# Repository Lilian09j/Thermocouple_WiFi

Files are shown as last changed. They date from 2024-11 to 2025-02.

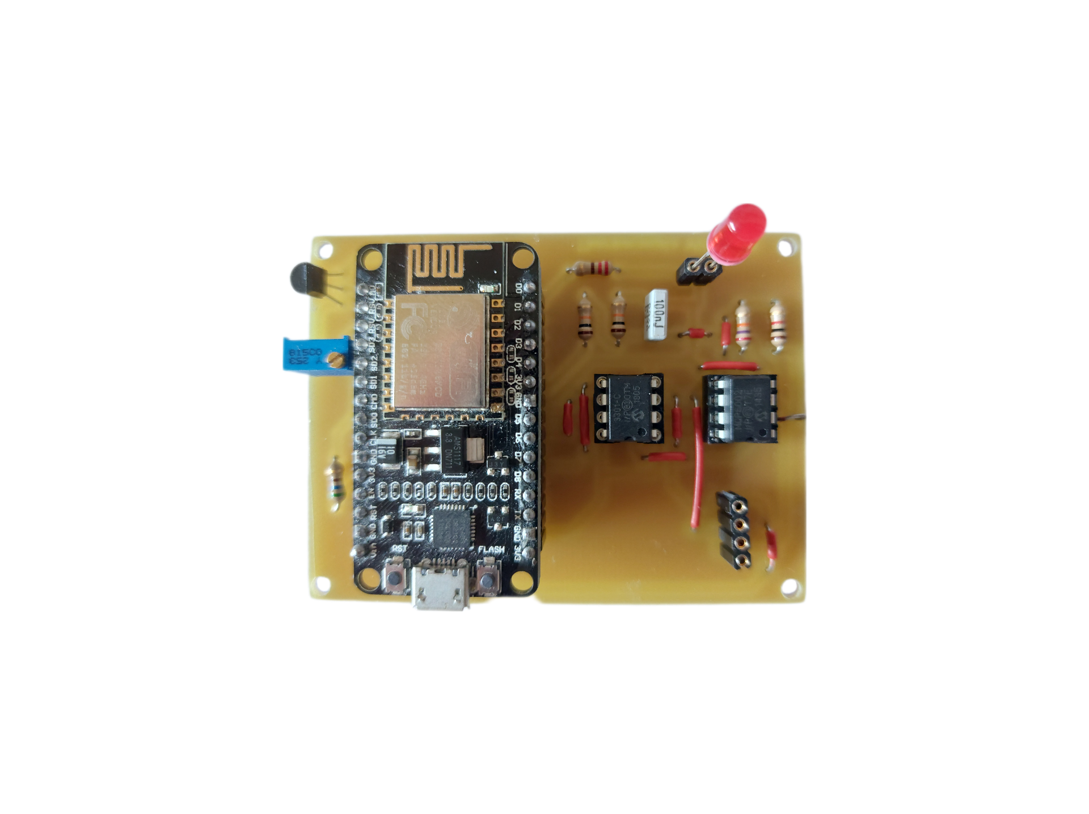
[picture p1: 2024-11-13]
Images/PCB_top_face_with_components.png

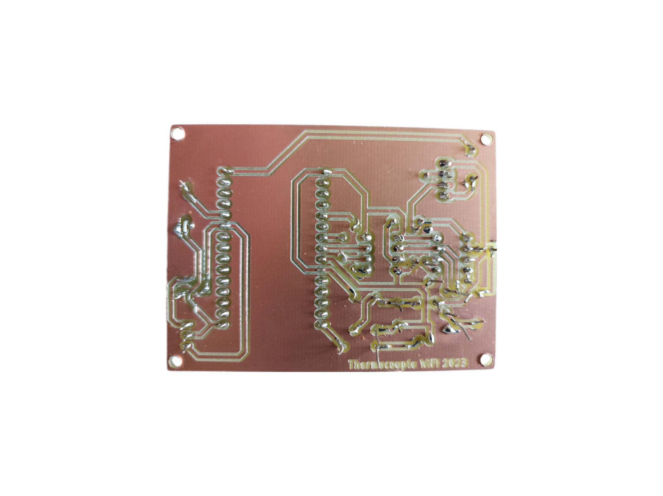
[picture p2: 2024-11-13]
Images/PCB_bottom_face.png

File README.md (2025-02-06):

# Thermocouple_WiFi
Development of a type K thermocouple with wireless data acquisition via WiFi from a Java App

Cold junction temperature measured by an LM335Z, MCP6002 AOPs in differential assembly, voltage sampling with an MCP3301 14bits ADC

The components used are thoses : ESP8266 (nodeMCU), MCP3301, MCP6002 and LM335Z

JAOUANNE Lilian & GARCON Bastian

Développement d'un thermocouple de type K basé sur un ESP8266 avec acquisition WiFi depuis une application Java

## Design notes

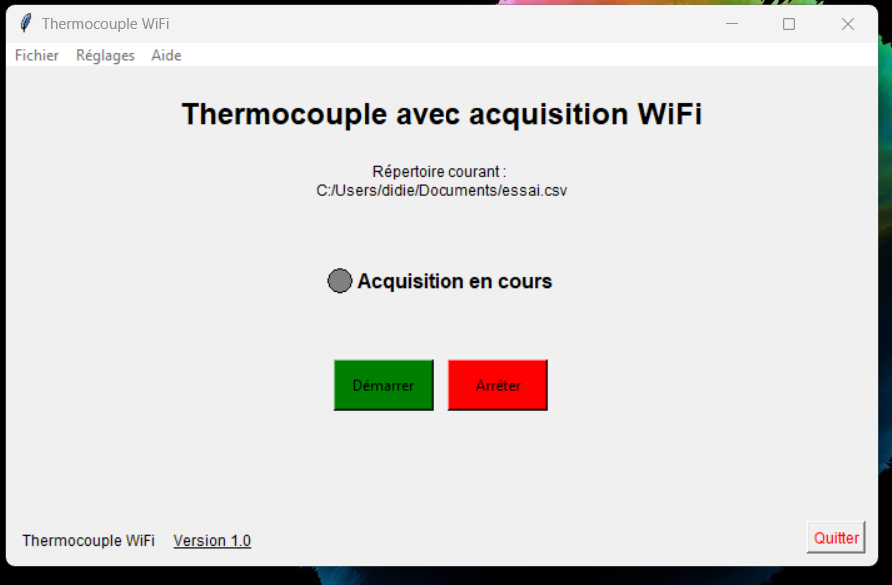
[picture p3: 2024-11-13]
Images/Python_Tkinter_App_Interface.png

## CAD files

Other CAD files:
Thermocouple_Fusion360_Modelisation/Boitier_3-piles-AAA.f3d
Thermocouple_Fusion360_Modelisation/Boitier_Thermocouple_V1.f3d
Thermocouple_Fusion360_Modelisation/Connecteur_Thermocouple_femelle.f3d
Thermocouple_Fusion360_Modelisation/Switch_KCD1-11_2pin.f3d

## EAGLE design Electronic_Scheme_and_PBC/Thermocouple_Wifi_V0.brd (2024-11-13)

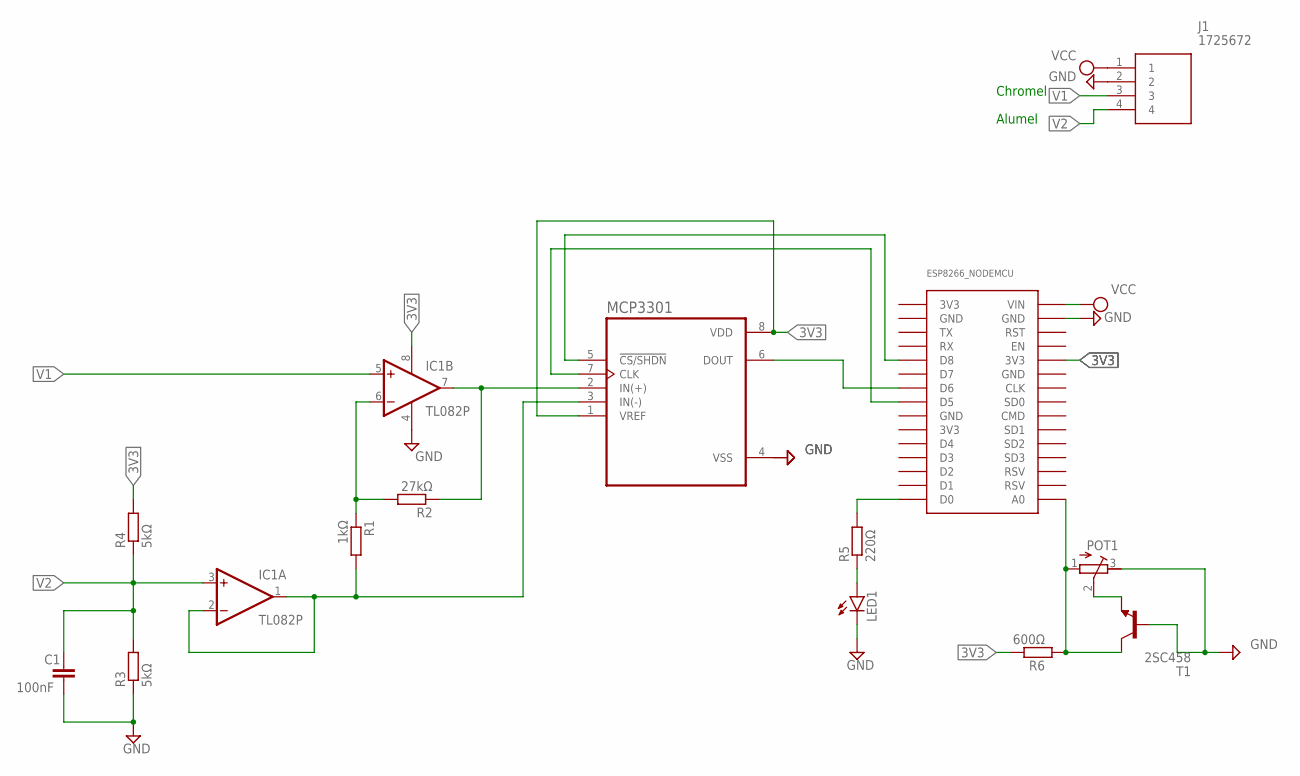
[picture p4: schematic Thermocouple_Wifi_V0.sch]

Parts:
C1: 100nF; C050-025X075
ESP8266_NODEMCU: NODEMCU_ESP8266
IC1: TL082P; DIL08
J1: 1725672; 1725672-4-2.54
LED1: LED5MM
MCP3301: MCP3301-CI/P; DIP787W46P254L927H533Q8
POT1: R-TRIMM74W; RTRIM74W
R1: 1kΩ; 0204/7
R2: 27kΩ; 0204/7
R3, R4: 5kΩ; 0204/7
R5: 220Ω; 0204/7
R6: 600Ω; 0204/7
T1: 2SC458; TO92-ECB

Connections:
3V3: ESP8266_NODEMCU.3V3@1 (3V3), ESP8266_NODEMCU.3V3@2 (3V3), ESP8266_NODEMCU.3V3@3 (3V3), IC1.8 (V+), MCP3301.1 (VREF), MCP3301.8 (VDD), R4.2, R6.2
GND: C1.2, ESP8266_NODEMCU.GND@1 (GND), ESP8266_NODEMCU.GND@2 (GND), ESP8266_NODEMCU.GND@3 (GND), ESP8266_NODEMCU.GND@4 (GND), IC1.4 (V-), J1.2, LED1.K (C), MCP3301.4 (VSS), POT1.3 (E), R3.1, T1.B
unnamed: ESP8266_NODEMCU.D5, MCP3301.7 (CLK)
unnamed: ESP8266_NODEMCU.A0, POT1.1 (A), R6.1, T1.C
unnamed: ESP8266_NODEMCU.D6, MCP3301.6 (DOUT)
unnamed: ESP8266_NODEMCU.D8, MCP3301.5 (!CS/SHDN)
unnamed: LED1.A, R5.1
unnamed: POT1.2 (S), T1.E
unnamed: IC1.7 (OUT), MCP3301.2 (IN(+)), R2.1
unnamed: IC1.1 (OUT), IC1.2 (-IN), MCP3301.3 (IN(-)), R1.2
unnamed: ESP8266_NODEMCU.D0, R5.2
unnamed: IC1.6 (-IN), R1.1, R2.2
V1: IC1.5 (+IN), J1.3
V2: C1.1, IC1.3 (+IN), J1.4, R3.2, R4.1
VCC: ESP8266_NODEMCU.VIN, J1.1

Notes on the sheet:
Chromel
Alumel

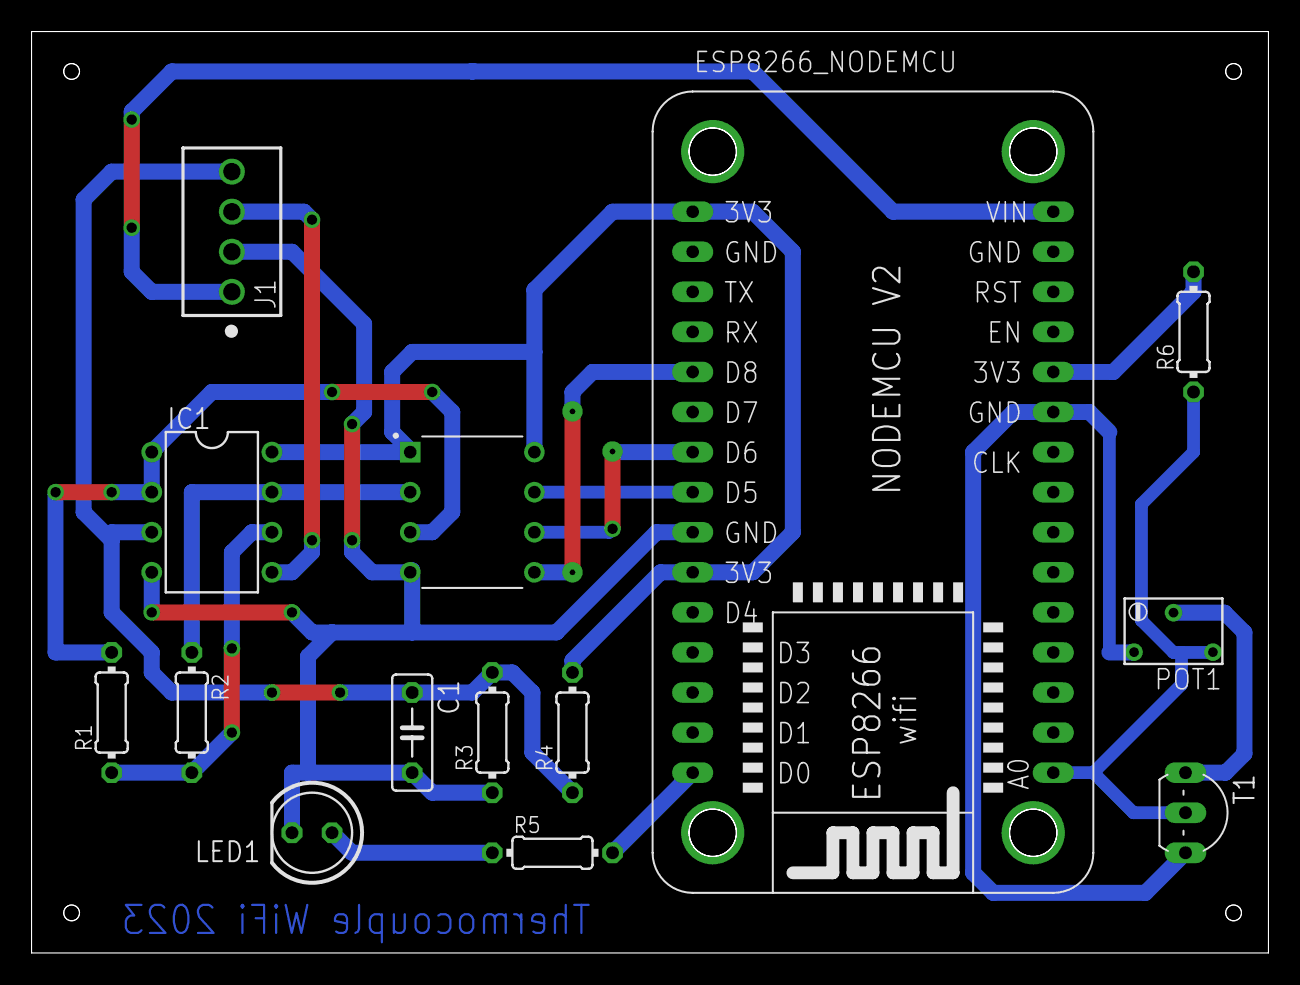
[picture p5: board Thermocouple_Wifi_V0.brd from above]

Board: 2 copper layers, 78.4 x 58.4 mm, 14 parts (0 on the bottom side), 15 nets.

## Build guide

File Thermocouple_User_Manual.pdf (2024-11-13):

Lilian JAOUANNE & Bastian GARCON | 04/2023

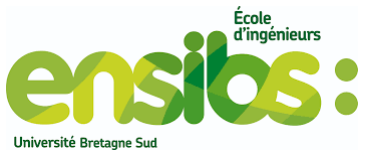
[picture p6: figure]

PEI2 / L2-SNIO – PRJ1401

# Manuel d’utilisation

1. Mise sous tension du dispositif thermocouple en faisant basculer la position de l’interrupteur présent sur le boitier.

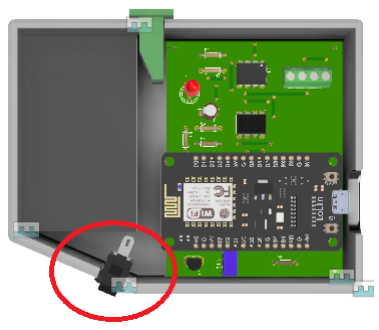
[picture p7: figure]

2. Brancher le connecteur du thermocouple de type K au bornier du boitier.

# Thermocouple WiFi

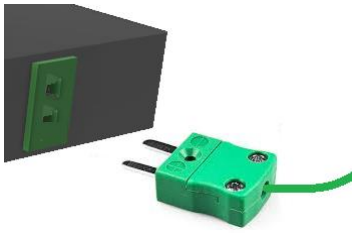
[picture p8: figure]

3. Lancer l’application « ThermoWiFi » sur un ordinateur, puis connecter l’ordinateur en question au point d’accès WiFi généré par l’ESP8266 du dispositif du thermocouple à l’aide des informations suivantes :
- SSID : Thermocouple-WiFi
- Password : ENSIBS2023

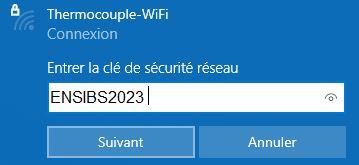
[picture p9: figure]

4. Calibrer le capteur de température de la soudure froide du thermocouple depuis la barre de menu de l’application sous « Réglages » puis « Soudure froide ».

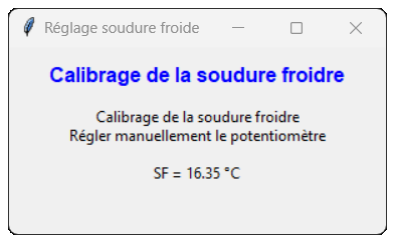
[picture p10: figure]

Ouvrir le boitier du thermocouple et se munir d’un tournevis pour faire tourner le potentiomètre présent sur le circuit intégré du thermocouple, jusqu’à obtenir sur la valeur de la température ambiante dans la fenêtre de l’application, puis fermer la fenêtre.

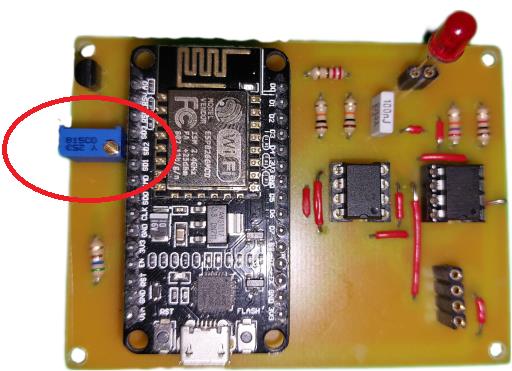
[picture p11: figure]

5. Choisir un fichier au format « csv » (format Excel) dans lequel sauvegarder les valeurs lors de la mesure.
La sélection / création du fichier se fait depuis la barre de menu sous « Fichier » puis « Enregistrer ». Le chemin du fichier courant doit alors être affiché sur la fenêtre principale de l’application.
6. Lancer l’acquisition de données en cliquant sur le bouton « Start » et arrêter l’acquisition une fois les mesures effectuées en cliquant sur le bouton « Stop ». Remarque : La LED présente sur dessus du boitier du thermocouple clignotera durant l’acquisition.

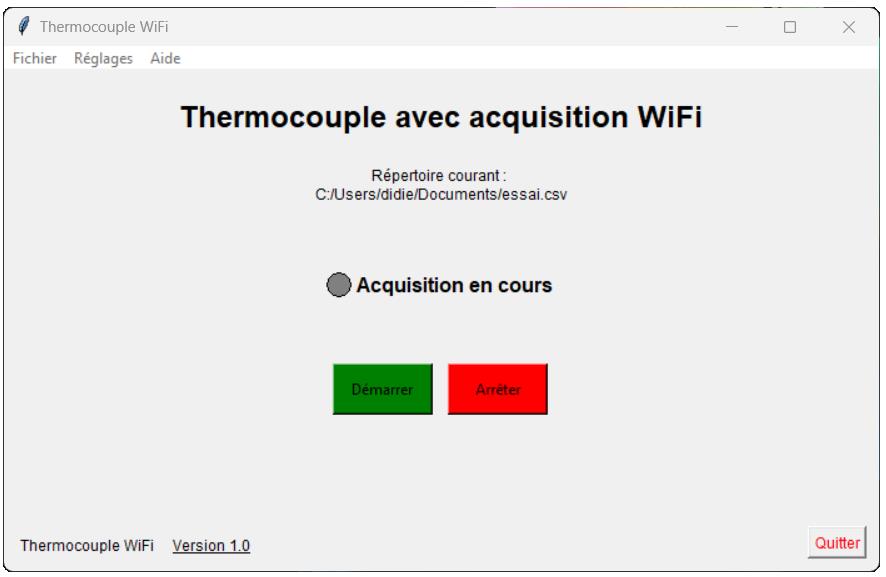
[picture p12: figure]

7. Vous pouvez ensuite consulter / mettre en forme les données obtenues (valeurs de températures de la soudure chaude (en °C) en fonction du temps (en ms)) directement depuis l’application sous « Fichier » puis « Ouvrir » ou depuis votre explorateur de fichiers.

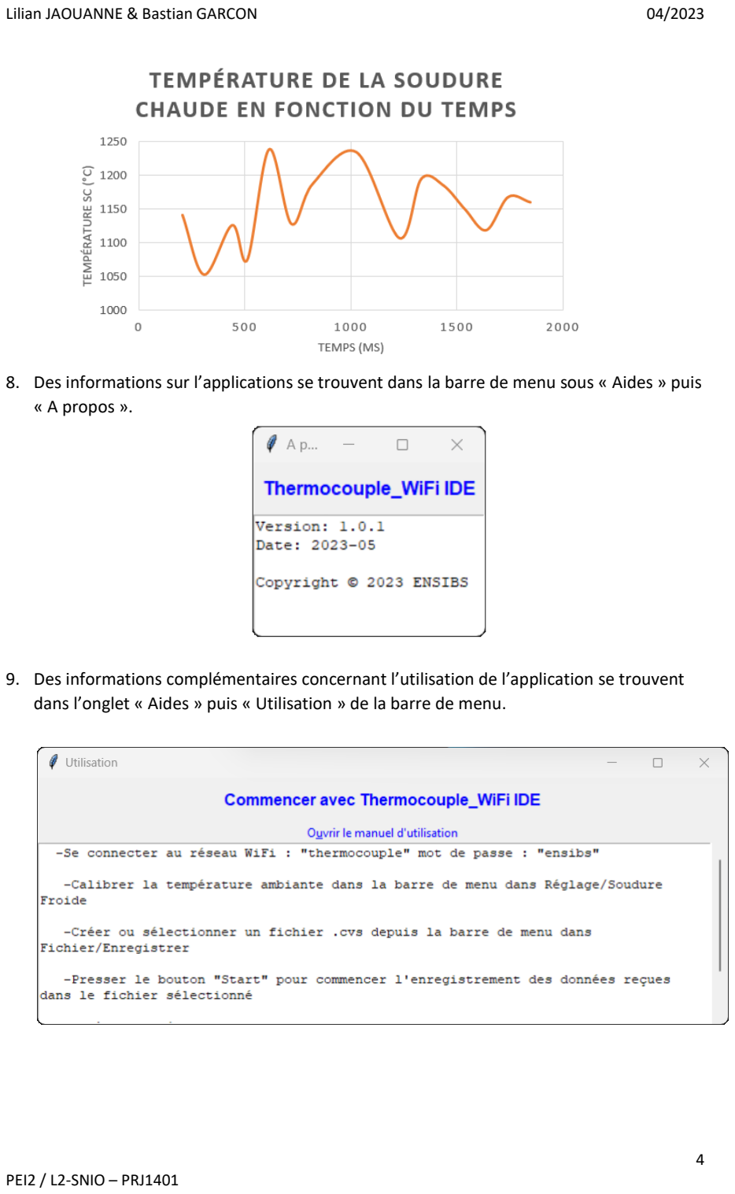
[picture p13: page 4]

8. Des informations sur l’applications se trouvent dans la barre de menu sous « Aides » puis « A propos ».
9. Des informations complémentaires concernant l’utilisation de l’application se trouvent dans l’onglet « Aides » puis « Utilisation » de la barre de menu.

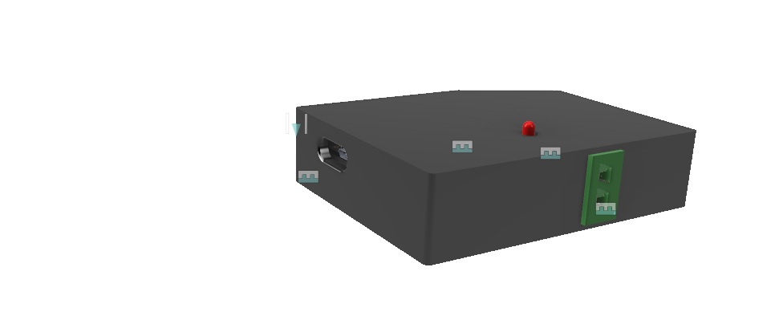
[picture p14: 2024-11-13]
Images/Assemblage_Thermocouple_v9.png

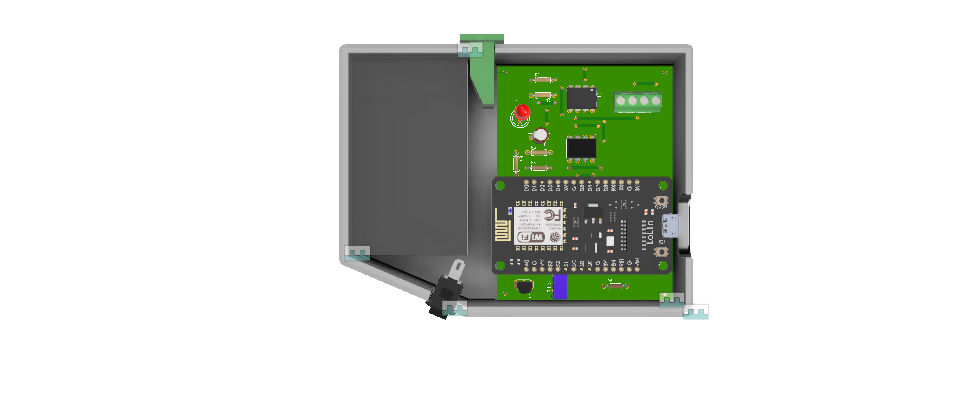
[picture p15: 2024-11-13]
Images/Assemblage_Thermocouple_v8.png

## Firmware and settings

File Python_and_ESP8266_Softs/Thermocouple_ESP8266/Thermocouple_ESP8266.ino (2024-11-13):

/* Create a WiFi access point and provide a web server on it.
Just a little test message.  Go to http://192.168.4.1 in a web browser
   connected to this access point to see it.*/   
#include <ESP8266WiFi.h>
#include <SPI.h>

#define Vref 3.3 // tension de reference du MCP3301 en V ici 3.3V
#define Gain 56.22 // gain de l'amplification de la tension mesuree résultant du circuit des 2 AOP = 28.11 mais en pratique environ le double

int led = D0; //led sur le pin D0
const int csPin = D8;  // Chip Select MCP3301
const char *ssid = "Thermocouple-WiFi";// Identifiant WiFi
const char *password = "ENSIBS2023";// Mot de passe WiFi
const int LM335 = A0;

bool sign=0;
int i=0, adcValue=0, z=0;
float tempSF=0, maxi=0, tensionmV=0, mini=0, moy=0, acc=0;

byte highByte=0x00, lowByte=0x00;

// Définir le port de communication TCP
const int serverPort = 12345;

// Créer un objet WiFiServer sur le port spécifié
WiFiServer server(serverPort);

void setup() {
  Serial.begin(115200);
  SPI.begin();
  pinMode(led, OUTPUT); //Instanciation de la LED comme une sortie
  digitalWrite(led, HIGH);
  pinMode(csPin, OUTPUT);
  pinMode(LM335, INPUT);
  digitalWrite(csPin, HIGH);  // Désactive le MCP3301 (slave)
  
  //Creation du point d acces wifi AP
  Serial.print("Configuring access point...");
  /* You can remove the password parameter if you want the AP to be open. */
  WiFi.softAP(ssid, password);
  IPAddress myIP = WiFi.softAPIP();
  Serial.print("AP IP address: ");
  Serial.println(myIP);
  // Commencer à écouter sur le port spécifié
  server.begin();
  Serial.print("Serveur en ecoute sur le port ");
  Serial.println(serverPort);
  Serial.print("En attente de connexions clients");

  delay(100);
  digitalWrite(led, LOW);
}

void loop() {
  digitalWrite(led, LOW);
  // Verifier si un client est connecte
  WiFiClient client = server.available();
  if (client) {
    Serial.println("Nouvelle connexion");
    while (client.connected()) {
      if(z%20==0){digitalWrite(led, HIGH); z=1;}//allume la led tous les 20 cycles d'émissions
      //Gestion mesure Soudure Froidre SF
      tempSF = analogRead(LM335)*3.3/1023;//Converti la valeur numerique en tension
      tempSF = tempSF*100-273;//Tension > kelvin > celsius (temperature soudure froide SF)
      Serial.print("SF : ");Serial.print(tempSF);Serial.println(" °C");
      if(tempSF >= maxi){maxi=tempSF;}
      if(tempSF <= mini | i==1){mini=tempSF;}
      acc += tempSF;
      moy = acc / i;
      i++;

      //Gestion mesure Soudure Chaude SC
      digitalWrite(csPin, LOW);  // Active le MCP3301 (slave)
      // Lit les deux octets de données renvoyés par le MCP3301
      highByte = SPI.transfer(0);
      lowByte = SPI.transfer(0);
      digitalWrite(csPin, HIGH); // Désactive le MCP3301
      // Calcule la valeur de tension à partir des octets lus
      sign = ((highByte << 8) | lowByte) & 0x1000;
      adcValue = ((highByte << 8) | lowByte) & 0x0FFF;//le 13eme bit est le bit de signe
      if(sign==0){//tension positive
        tensionmV = 1000 * adcValue * Vref / 4096 / Gain;
        // Affiche la valeur de tension sur la console serie
        Serial.print("signe : ");Serial.print(sign, BIN);Serial.print("   adcValue : ");Serial.println(adcValue, BIN);
        Serial.print("Tension : ");Serial.print(tensionmV);Serial.println(" mV");
        // Envoyer des données au client
        String data = String(tensionmV) + "," + String(tempSF);
        client.print(data);
        delay(50);
        digitalWrite(led, LOW); 
        delay(50);// periode 100ms soit 10Hz de frequence de transmission
        z++;
        }
      else if(sign==1){//tension negative
        tensionmV = 1000 * (-4096 + adcValue) * Vref / 4096 / Gain;//Complement a deux
        Serial.print("signe : ");Serial.print(sign, BIN);Serial.print("   adcValue : ");Serial.println(adcValue, BIN);
        Serial.print("Tension : ");Serial.print(tensionmV);Serial.println(" mV");
        String data = String(tensionmV) + "," + String(tempSF);
        client.print(data);
        delay(50);
        digitalWrite(led, LOW);     
        delay(50);
        z++;
        }
      else{Serial.print("erreur signe");}
    }
    
    Serial.println("Connexion terminee");
    WiFi.softAPdisconnect(true);//arret du point d acces
    Serial.println("Point d'accès WiFi fermé");
    server.close();
        
    //Creation du point d acces wifi AP
    Serial.print("Configuring access point...");
    /* You can remove the password parameter if you want the AP to be open. */
    WiFi.softAP(ssid, password);
    IPAddress myIP = WiFi.softAPIP();
    Serial.print("AP IP address: ");
    Serial.println(myIP);
    // Commencer à écouter sur le port spécifié
    server.begin();
    Serial.print("Serveur en ecoute sur le port ");
    Serial.println(serverPort);
    Serial.print("En attente de connexions clients");
  }

  delay(500);
  Serial.print(".");
  digitalWrite(led, 0);
}
